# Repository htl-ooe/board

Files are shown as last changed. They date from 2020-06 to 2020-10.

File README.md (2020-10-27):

# HTL OOE HAT for Raspberry Pi
board schematic, layout and instructions on how to operate the board

## Installing the Operating System

### Downloading the Operating System
There are lots of operating Systems (Distributions) for the Raspberry Pi. Most of them are based on Linux.
The Foundation’s official supported operating system is [Raspberry Pi OS](https://www.raspberrypi.org/downloads/raspberry-pi-os/ "Raspberry Pi OS").
There are 3 Variants:
  * [Raspberry Pi OS with desktop and recommended software](https://downloads.raspberrypi.org/raspios_full_armhf_latest "Raspberry Pi OS full")
  * [Raspberry Pi OS with desktop](https://downloads.raspberrypi.org/raspios_armhf_latest "Raspberry Pi OS with Desktop")
  * [Raspberry Pi OS Lite (just Console, smallest in size)](hhttps://downloads.raspberrypi.org/raspios_lite_armhf_latest "Raspberry Pi OS Lite")

In our case [Raspberry Pi OS with desktop](https://downloads.raspberrypi.org/raspios_armhf_latest "Raspberry Pi OS with Desktop") is the the best choice.
You can not just copy the files to a Micro SD Card to install the Operating System. To boot Raspberry Pi OS you have to install the Operating System on the Micro SD Card.
Look at [Installing operating system images](https://www.raspberrypi.org/documentation/installation/installing-images/README.md "Installing operating system images") for how to do this. [balenaEtcher](https://www.balena.io/etcher/ "balena Etcher") installs itself to the Userprofile, take care of that when trying to use with different Accounts!
You will need administrative rights to format the Micro SD Card, so installing and using balena Etcher as Administrator is a good choice.
To be able to connect via ssh to the Raspberry Pi (headless) you can place the Files [ssh und wpa_supplicant.conf](https://www.raspberrypi.org/documentation/configuration/boot_folder.md "ssh und wpa_supplicant.conf") in the boot Folder of the Micro SD Card during the verify Cycle of  balena Etcher.
When using a SD Card to Micro SD Card Adapter, there is a Switch called **LOCK**. Take care, that the Switch is in the unlocked position (balena Etcher will tell you if the Micro SD Card is write protected).
When you access the Micro SD Card using Microsoft Windows, it asks for **formatting** the Device. **Don't do this!**
Now you can power up the Raspberry Pi with the plugged in Micro SD Card. If the Rasperry Pi is connected to a Monitor, you can you can read the Raspberry Pi's IP Address.
When you operate the Raspberry Pi headless you can use IP Scanners like the [Advanced IP Scanner](https://www.advanced-ip-scanner.com/ "Advanced IP Scanner") to get the IP Address.
Transfering Files is easy with [WinSCP](https://winscp.net/eng/download.php "WinSCP"). You can start a Terminal Program from within WinSCP itself or download [PuTTY](https://www.chiark.greenend.org.uk/~sgtatham/putty/latest.html "PuTTY").
When connected, you can enable **VNC** via
```console
pi@raspberrypi:~ $ sudo raspi-config
```
and use a Viewer like [VNC Viewer](https://www.realvnc.com/en/connect/download/viewer/ "VNC Viewer")

### Updating the Operating System and Installing Software

#### preparing APT for use with an Proxy
Create a new File called proxy.conf and edit it. You can use an Editor like **nano** or **vi**
```console
pi@raspberrypi:~ $ sudo touch /etc/apt/apt.conf.d/proxy.conf
pi@raspberrypi:~ $ sudo vi /etc/apt/apt.conf.d/proxy.conf
```
Add the following Lines to the empty File:
```code
Acquire {
  HTTP::proxy "http://proxy.htl-steyr.ac.at:8082/";
  HTTPS::proxy "https://proxy.htl-steyr.ac.at:8082/";
}
```
If you do not need the proxy (e.g. at home), you can just rename the File to disable the proxy:
```console
pi@raspberrypi:~ $ sudo mv /etc/apt/apt.conf.d/proxy.conf /etc/apt/apt.conf.d/proxy.conf.htl
```
#### Using APT
Using **apt-get** (Advanced Packaging Tool) you can update the Operating System and install Software.
The most important apt-get commands are:
| command | description |
| --- | --- |
| update | downloads the package lists from the repositories |
| upgrade | updates the list of available packages and their versions |
| install | installs one or more program package(s) |
| purge | removes a program package including the configuration|
apt-get needs the time and date to be set to an actual value! You can do this by typing
```console
pi@raspberrypi:~ $ sudo date -s "13 Jun 2020 09:20:00"
pi@raspberrypi:~ $ date # returns current time and date
```
If you have a ntp timeserver up and running you can edit
```console
pi@raspberrypi:~ $ sudo vi /etc/systemd/timesyncd.conf
```
to update the time via network.

To do the necessary software Maintenance you should enter
```console
pi@raspberrypi:~ $ sudo apt-get -y update && sudo apt-get -y dist-upgrade
```
Setting the Time Zone and enabling ntp (network time protocol)
```console
pi@raspberrypi:~ $ sudo timedatectl set-timezone Europe/Vienna
pi@raspberrypi:~ $ sudo timedatectl set-ntp true
```

## Device Tree
To manage ressources Linux uses the [Device Tree](https://www.raspberrypi.org/documentation/configuration/device-tree.md "Device Tree"). Parts of it are configured in the File [config.txt](https://www.raspberrypi.org/documentation/configuration/config-txt/README.md "config.txt").
You can also add devices via the EEPROM on a [HAT](https://github.com/raspberrypi/hats "HAT").
To configure devices [virtual Filesystems](https://en.wikipedia.org/wiki/Virtual_file_system "virtual Filesystems") (/dev, /sys, /proc) are frequently used.
### PWM
Our HAT uses PWM channels. The **root** user can access the onboard chanels.
If the user **pi** should use the pripheral, you have to give him the rights to do this:
Edit the File `/etc/udev/rules.d/99-com.rules`
```console
pi@raspberrypi:~ $ sudo vi /etc/udev/rules.d/99-com.rules
```
and change
```code
        chown -R root:gpio /sys/devices/platform/soc/*.pwm/pwm/pwmchip* && chmod -R 770 /sys/devices/platform/soc/*.pwm/pwm/pwmchip*\
```
to
```code
        chown -R root:gpio /sys/devices/platform/soc/*.pwm/pwm/pwmchip* && chmod -R 770 /sys/devices/platform/soc/*.pwm/pwm/pwmchip*;\
        chown -R root:gpio /sys/devices/platform/soc/*.i2c/i2c*/*/pwm/pwmchip* && chmod -R 770 /sys/devices/platform/soc/*.i2c/i2c*/*/pwm/pwmchip*\
```
mind the semicolon **;** to be added to the first Line!

Controlling the PWM Unit can be done in the virtual Filesystem `/sys/class/pwm/pwmchip*`.
When using **Python** [python-periphery](https://python-periphery.readthedocs.io/ "python-periphery") can access the PWM channels.
Keyboard, Mouse, Joysticks and Game Controllers can easily be accessed using [python-evdev](https://python-evdev.readthedocs.io/ "python-evdev")
#### Programing the HAT EEPROM
Download the latest Version of the **eepromutils** and compile the utils. You can also download the Repository (zip file) and unzip them in pi's homedirectory. Then you have to rename the directorys, so they do not contain "-master".
```console
pi@raspberrypi:~ $ sudo apt-get install -y git
pi@raspberrypi:~ $ git clone https://github.com/raspberrypi/hats.git
pi@raspberrypi:~ $ git clone https://github.com/htl-ooe/board.git
pi@raspberrypi:~ $ cd hats/eepromutils && make ; cd
```
```console
pi@raspberrypi:~ $ sudo dtc -@ -H epapr -O dtb -o "/boot/overlays/smartcar-V1-2.dtbo" -W no-unit_address_vs_reg './board/hat/smartcar-V1-2-overlay.dts'
```
compiles the device tree source file and copies it to `/boot/overlays`. You can test the overlayfile by adding the line
`dtoverlay=smartcar-V1-2` to [config.txt](https://www.raspberrypi.org/documentation/configuration/config-txt/README.md "config.txt")
```console
pi@raspberrypi:~ $ ./hats/eepromutils/eepmake ./board/hat/eeprom_settings-V1-2.txt ./board/hat/smartcar-V1-2.eep /boot/overlays/smartcar-V1-2.dtbo
```
generates the contents of the EEPROM

Disable the write protection with a piece of wire or calipers: 
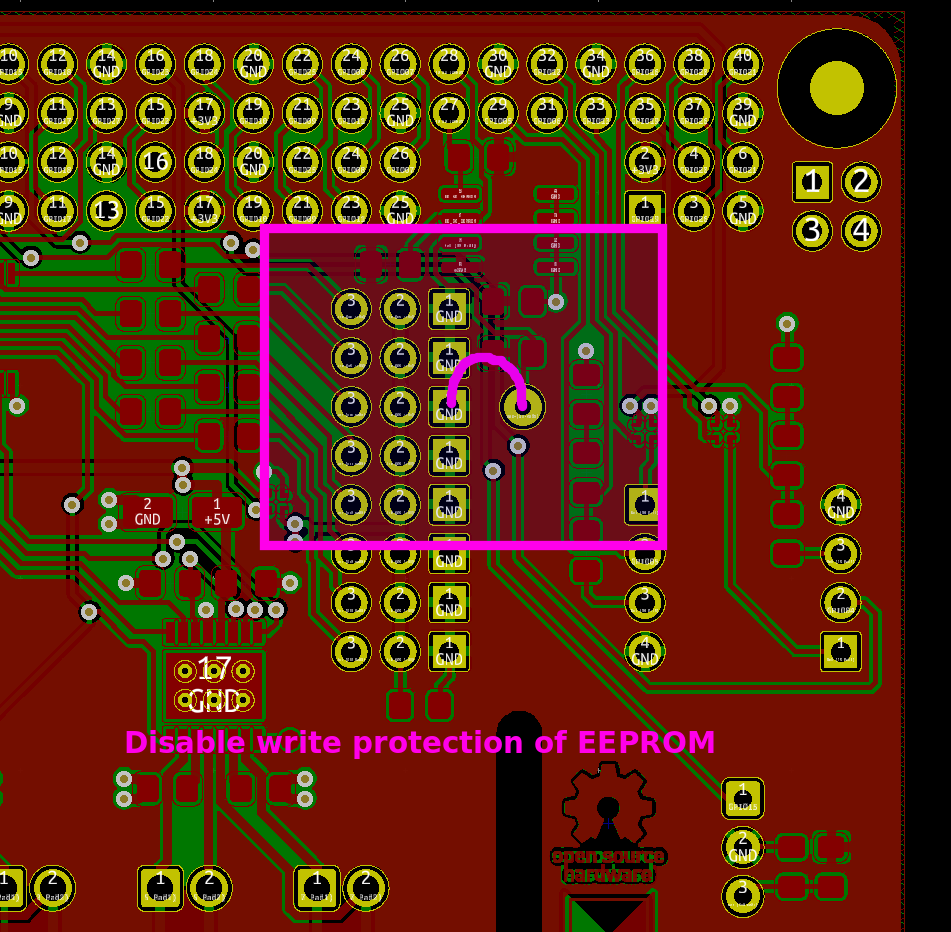
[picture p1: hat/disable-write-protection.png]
Disable the write protection


```console
pi@raspberrypi:~ $ sudo ./hats/eepromutils/eepflash.sh -w -f=./board/hat/smartcar-V1-2.eep -t=24c512
```
writes smartcar-V1-2.eep to the EEPROM, assumed that you disabled the Write Protection and i2c-0 can be enabled. Propably you need dtparam=i2c_vc=on in [config.txt](https://www.raspberrypi.org/documentation/configuration/config-txt/README.md "config.txt").

#### Reboot
```
pi@raspberrypi:~ $ sudo reboot
```

## Ultrasonic Sensors
### Compile modules install toolchain and headers
```console
pi@raspberrypi:~ $ sudo apt-get install -y raspberrypi-kernel-headers
```
installs the header Files for the Kernel
```console
pi@raspberrypi:~ $ git clone https://github.com/htl-ooe/board.git
pi@raspberrypi:~ $ sudo /home/pi/board/drivers/install.sh
```
compiles the srf04.c File and copies it to the propper directory. When you did this once you can copy the compiled module to another Raspberry Pi and do not have to compile (download the rpi headers) again.
## IR Receiver
install ir-keytable
```console
pi@raspberrypi:~ $ sudo apt-get install -y ir-keytable
```
select the desired Protocol (templates: /lib/udev/rc_keymaps) eg: rc6_mce
```console
pi@raspberrypi:~ $ sudo ir-keytable -p rc-5,rc-5-sz,jvc,sony,nec,sanyo,mce_kbd,rc-6,sharp,xmp -w /lib/udev/rc_keymaps/rc6_mce.toml
```
to test type
```console
pi@raspberrypi:~ $ ir-keytable --test
```
to bind actions (triggers) to a IR Key edit eg. /etc/triggerhappy/triggers.d/power.conf (new File)
and add the line **KEY_POWER		1	sudo /sbin/halt** to shutdown with the power key

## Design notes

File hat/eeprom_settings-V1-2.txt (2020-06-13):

########################################################################
# EEPROM settings text file
#
# Edit this file for your particular board and run through eepmake tool,
# then use eepflash tool to write to attached HAT ID EEPROM 
#
# Tools available:
#  eepmake   Parses EEPROM text file and creates binary .eep file
#  eepdump   Dumps a binary .eep file as human readable text (for debug)
#  eepflash  Write or read .eep binary image to/from HAT EEPROM
#
########################################################################

########################################################################
# Vendor info

# 128 bit UUID. If left at zero eepmake tool will auto-generate
# RFC 4122 compliant UUID
product_uuid 00000000-0000-0000-0000-000000000000

# 16 bit product id
product_id 0x0002

# 16 bit product version
product_ver 0x0001

# ASCII vendor string  (max 255 characters)
vendor "HTL Steyr"

# ASCII product string (max 255 characters)
product "Smart Car V1.2"

########################################################################
# GPIO bank settings, set to nonzero to change from the default.
# NOTE these setting can only be set per BANK, uncommenting any of
# these will force the bank to use the custom setting.

# drive strength, 0=default, 1-8=2,4,6,8,10,12,14,16mA, 9-15=reserved
gpio_drive 0

# 0=default, 1=slew rate limiting, 2=no slew limiting, 3=reserved
gpio_slew 0

# 0=default, 1=hysteresis disabled, 2=hysteresis enabled, 3=reserved
gpio_hysteresis 0

# If board back-powers Pi via 5V GPIO header pins:
# 0 = board does not back-power
# 1 = board back-powers and can supply the Pi with a minimum of 1.3A
# 2 = board back-powers and can supply the Pi with a minimum of 2A
# 3 = reserved
# If back_power=2 then USB high current mode will be automatically 
# enabled on the Pi
back_power 0

########################################################################
# GPIO pins, uncomment for GPIOs used on board
# Options for FUNCTION: INPUT, OUTPUT, ALT0-ALT5
# Options for PULL: DEFAULT, UP, DOWN, NONE
# NB GPIO0 and GPIO1 are reserved for ID EEPROM so cannot be set

#         GPIO  FUNCTION  PULL
#         ----  --------  ----
setgpio  2     ALT0     DEFAULT
setgpio  3     ALT0     DEFAULT
setgpio  4     OUTPUT     DEFAULT
setgpio  5     OUTPUT     DEFAULT
setgpio  6     INPUT     DEFAULT
#setgpio  7     INPUT     DEFAULT
#setgpio  8     INPUT     DEFAULT
#setgpio  9     INPUT     DEFAULT
#setgpio  10    INPUT     DEFAULT
#setgpio  11    INPUT     DEFAULT
setgpio  12    OUTPUT     DOWN
setgpio  13    OUTPUT     DOWN
#setgpio  14    INPUT     DEFAULT
setgpio  15    INPUT     DEFAULT
setgpio  16    INPUT     DEFAULT
#setgpio  17    INPUT     DEFAULT
#setgpio  18    INPUT     DEFAULT
#setgpio  19    INPUT     DEFAULT
#setgpio  20    INPUT     DEFAULT 
#setgpio  21    INPUT     DEFAULT 
#setgpio  22    INPUT     DEFAULT
setgpio  23    OUTPUT     DEFAULT
#setgpio  24    INPUT     DEFAULT
#setgpio  25    INPUT     DEFAULT
#setgpio  26    INPUT     DEFAULT
setgpio  27    OUTPUT     DEFAULT

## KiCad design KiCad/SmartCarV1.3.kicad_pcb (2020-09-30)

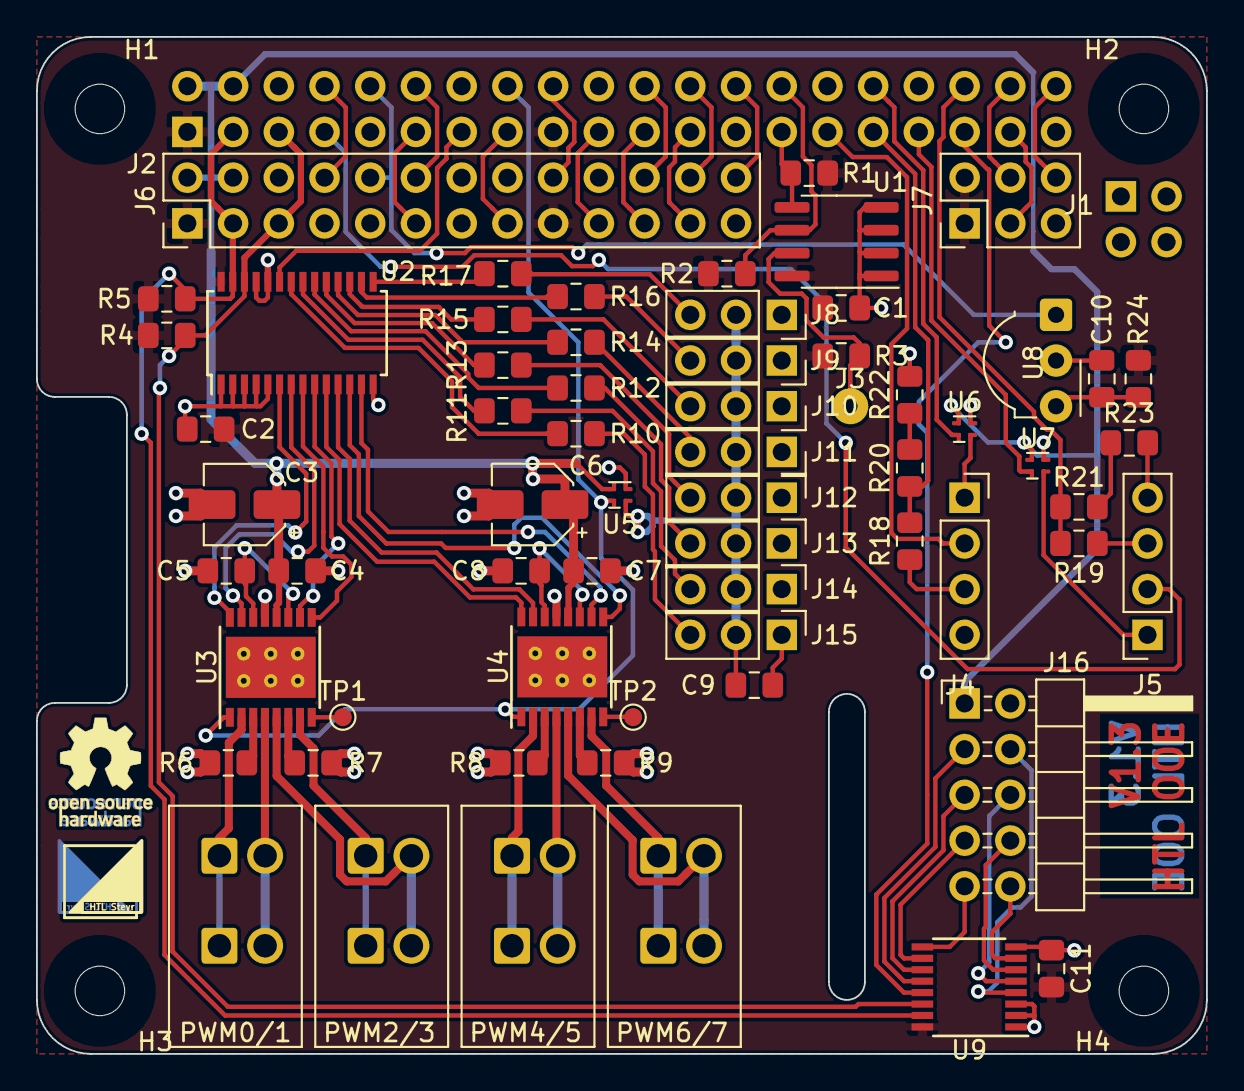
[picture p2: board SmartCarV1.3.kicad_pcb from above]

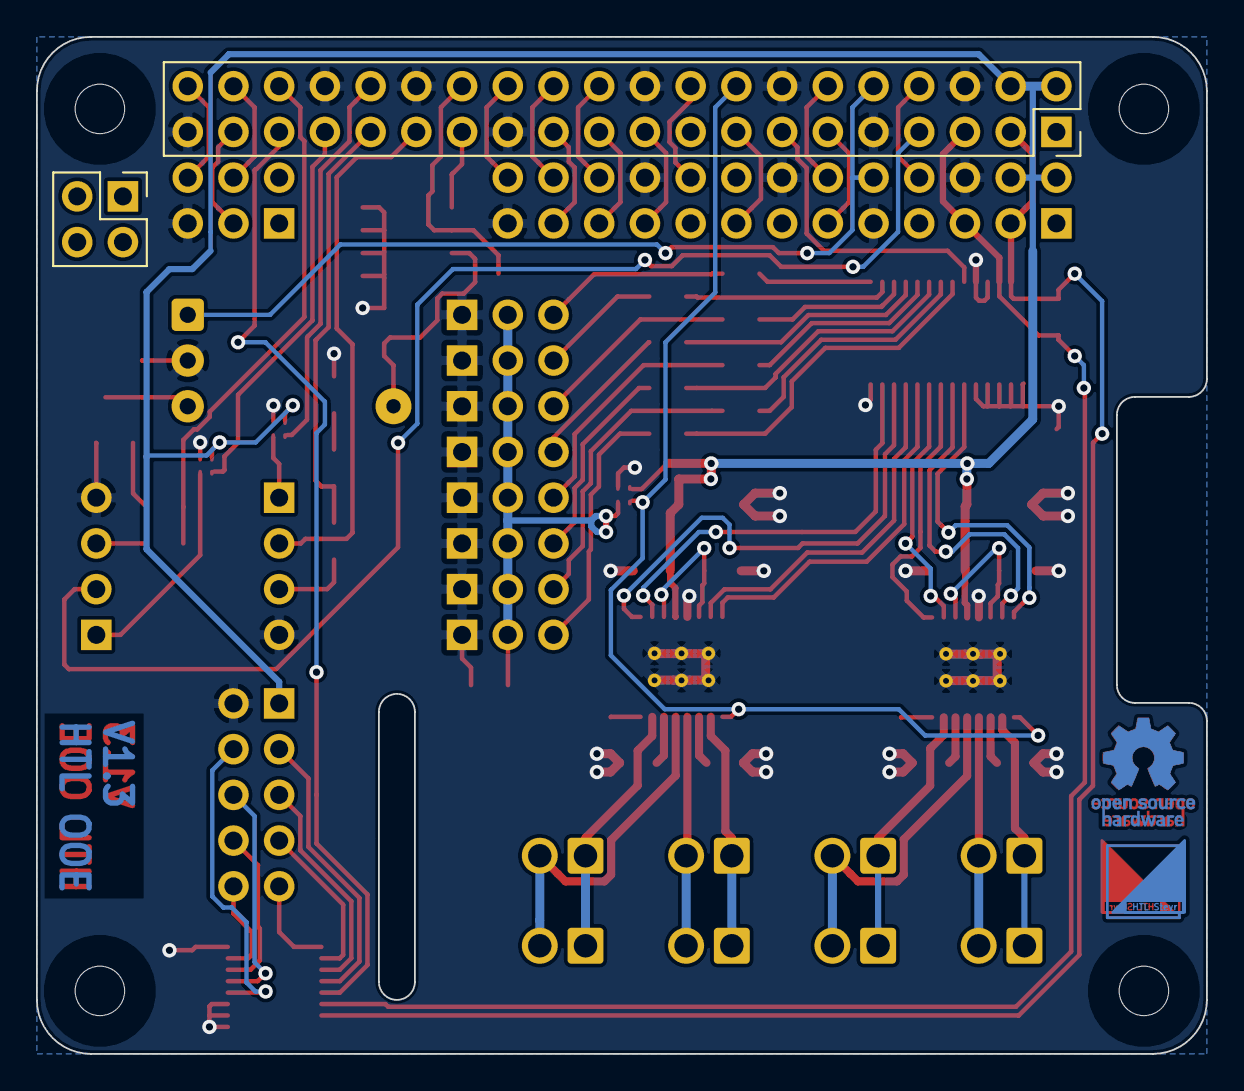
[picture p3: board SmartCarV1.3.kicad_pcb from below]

Board: 2 copper layers, 65.0 x 56.5 mm, 76 parts (4 on the bottom side), 88 nets.

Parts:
C1, C2, C4, C7, C9, C10, C11: 100nF; C_0805_2012Metric_Pad1.15x1.40mm_HandSolder
C3, C6: 10uF; CP_Elec_4x5.7
C5, C8: 2,2uF; C_0805_2012Metric_Pad1.15x1.40mm_HandSolder
H1, H2, H3, H4: MountingHole; MountingHole_2.7mm_M2.5
J1: PI4HAT; PinSocket_2x02_P2.54mm_Vertical
J2: PI40HAT; PinSocket_2x20_P2.54mm_Vertical
J3: Conn_01x01; SolderWirePad_1x01_Drill0.8mm
J4, J5: Conn_01x04; PinSocket_1x04_P2.54mm_Vertical
J6: Conn_02x13_Odd_Even; PinHeader_2x13_P2.54mm_Vertical
J7: Conn_02x03_Odd_Even; PinHeader_2x03_P2.54mm_Vertical
J8, J9, J10, J11: Conn_01x03; PinSocket_1x03_P2.54mm_Vertical
J12, J13, J14, J15: Conn_01x03; PinHeader_1x03_P2.54mm_Vertical
J16: Conn_02x05_Odd_Even; PinHeader_2x05_P2.54mm_Horizontal
Logo1, Logo3: HTL-Steyr-Logo_4x4mm_Copper
Logo2, Logo6: OSHW-Logo_5.7x6mm_Copper
Logo4: HTL-Steyr-Logo_4x4mm_SilkScreen
Logo7: OSHW-Logo_5.7x6mm_SilkScreen
PWM0/1, PWM2/3, PWM4/5, PWM6/7: Conn_01x02; TE_2834085-1_1x02_P2.54mm_45deg
R1, R2, R3, R4, R5, R18, R19, R20, R21, R22, R23: 3k9; R_0805_2012Metric_Pad1.15x1.40mm_HandSolder
R6, R7, R8, R9: 470m; R_0805_2012Metric_Pad1.15x1.40mm_HandSolder
R10, R11, R12, R13, R14, R15, R16, R17: 270; R_0805_2012Metric_Pad1.15x1.40mm_HandSolder
R24: 100; R_0805_2012Metric_Pad1.15x1.40mm_HandSolder
TP1, TP2: TestPoint_Probe; TestPoint_Pad_D1.0mm
U1: CAT24C512; SOIC-8_3.9x4.9mm_P1.27mm
U2: PCA9685PW; TSSOP-28_4.4x9.7mm_P0.65mm
U3, U4: DRV8848; HTSSOP-16-1EP_4.4x5mm_P0.65mm_EP3.4x5mm_Mask2.46x2.31mm_The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
U5, U6, U7: MIC94044YFL; MLF-4-1.2x1.2mm
U8: TSOP43xx; Vishay_MOLD-3Pin
U9: TCA9554DBQ; SSOP-16_3.9x4.9mm_P0.635mm

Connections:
+3V3: C1.1, C2.1, C11.2, J2.1, J2.17, J6.1, J6.17, J7.1, J7.2, R1.2, R2.2, R3.2, R4.2, R5.2, R24.1, U1.8, U2.28, U9.16
+5V: C3.1, C4.1, C6.1, C7.1, J2.2, J2.4, J6.2, J6.4, J16.1, U3.12, U4.12, U5.3, U6.3, U7.3
/GPIO04: J2.7, J5.2
/GPIO05: J2.29, J4.2
/GPIO06: J2.31, R18.2, R20.1
/GPIO07: J2.26, J6.26
/GPIO08: J2.24, J6.24
/GPIO09: J2.21, J6.21
/GPIO10: J2.19, J6.19
/GPIO11: J2.23, J6.23
/GPIO12: J2.32, U6.4
/GPIO13: J2.33, U7.4
/GPIO14: J2.8, J6.8
/GPIO15: J2.10, J6.10, U8.1
/GPIO16: J2.36, R19.2, R21.1
/GPIO17: J2.11, J6.11
/GPIO18: J2.12, J6.12
/GPIO19: J2.35, U9.13
/GPIO20: J2.38, J7.4
/GPIO21: J2.40, J7.6
/GPIO22: J2.15, J6.15
/GPIO23: J2.16, U3.1, U4.1, U5.4
/GPIO24: J2.18, J6.18
/GPIO25: J2.22, J6.22
/GPIO26: J2.37, J7.3
/GPIO27: J2.13, U2.23
/ID_SC_EEPROM: J2.28, R2.1, U1.6
/ID_SD_EEPROM: J2.27, R1.1, U1.5
/SCL1: J2.5, J6.5, R4.1, U2.26, U9.14
/SDA1: J2.3, J6.3, R5.1, U2.27, U9.15
GND: C1.2, C2.2, C3.2, C4.2, C5.2, C6.2, C7.2, C8.2, C9.2, C10.1, C11.1, J2.6, J2.9, J2.14, J2.20, J2.25, J2.30, J2.34, J2.39, J4.4, J5.4, J6.6, J6.9, J6.14, J6.20, J6.25, J7.5, J8.1, J9.1, J10.1, J11.1, J12.1, J13.1, J14.1, J15.1, J16.2, R6.2, R7.2, R8.2, R9.2, R22.2, R23.2, U1.1, U1.2, U1.3, U1.4, U2.1, U2.2, U2.3, U2.4, U2.5, U2.14, U2.24, U2.25, U3.13, U3.17, U4.13, U4.17, U5.2, U6.2, U7.2, U8.2, U9.1, U9.2, U9.3, U9.8
unnamed: C5.1, U3.11, U3.14
unnamed: C8.1, U4.11, U4.14
unnamed: C9.1, J8.2, J9.2, J10.2, J11.2, J12.2, J13.2, J14.2, J15.2, U5.1
unnamed: C10.2, R24.2, U8.3
unnamed: J3.1, R3.1, U1.7
unnamed: J4.1, U6.1
unnamed: J4.3, R18.1
unnamed: J5.1, U7.1
unnamed: J5.3, R19.1
unnamed: J8.3, R17.1
unnamed: J9.3, R16.1
unnamed: J10.3, R15.1
unnamed: J11.3, R14.1
unnamed: J12.3, R13.1
unnamed: J13.3, R12.1
unnamed: J14.3, R11.1
unnamed: J15.3, R10.1
unnamed: J16.3, U9.12
unnamed: J16.4, U9.4
unnamed: J16.5, U9.11
unnamed: J16.6, U9.5
unnamed: J16.7, U9.10
unnamed: J16.8, U9.6
unnamed: J16.9, U9.9
unnamed: J16.10, U9.7
unnamed: PWM0/1.1, U3.2
unnamed: PWM0/1.2, U3.4
unnamed: PWM2/3.1, U3.7
unnamed: PWM2/3.2, U3.5
unnamed: PWM4/5.1, U4.2
unnamed: PWM4/5.2, U4.4
unnamed: PWM6/7.1, U4.7
unnamed: PWM6/7.2, U4.5
unnamed: R6.1, U3.3
unnamed: R7.1, U3.6
unnamed: R8.1, U4.3
unnamed: R9.1, U4.6
unnamed: R10.2, U2.22
unnamed: R11.2, U2.21
unnamed: R12.2, U2.20
unnamed: R13.2, U2.19
unnamed: R14.2, U2.18
unnamed: R15.2, U2.17
unnamed: R16.2, U2.16
unnamed: R17.2, U2.15
unnamed: R20.2, R22.1
unnamed: R21.2, R23.1
unnamed: TP1.1, U3.8
unnamed: TP2.1, U4.8
unnamed: U2.6, U3.16
unnamed: U2.7, U3.15
unnamed: U2.8, U3.9
unnamed: U2.9, U3.10
unnamed: U2.10, U4.16
unnamed: U2.11, U4.15
unnamed: U2.12, U4.9
unnamed: U2.13, U4.10

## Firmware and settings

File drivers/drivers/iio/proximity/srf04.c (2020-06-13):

// SPDX-License-Identifier: GPL-2.0-or-later
/*
 * SRF04: ultrasonic sensor for distance measuring by using GPIOs
 *
 * Copyright (c) 2017 Andreas Klinger <ak@it-klinger.de>
 *
 * For details about the device see:
 * http://www.robot-electronics.co.uk/htm/srf04tech.htm
 *
 * the measurement cycle as timing diagram looks like:
 *
 *          +---+
 * GPIO     |   |
 * trig:  --+   +------------------------------------------------------
 *          ^   ^
 *          |<->|
 *         udelay(trigger_pulse_us)
 *
 * ultra           +-+ +-+ +-+
 * sonic           | | | | | |
 * burst: ---------+ +-+ +-+ +-----------------------------------------
 *                           .
 * ultra                     .              +-+ +-+ +-+
 * sonic                     .              | | | | | |
 * echo:  ----------------------------------+ +-+ +-+ +----------------
 *                           .                        .
 *                           +------------------------+
 * GPIO                      |                        |
 * echo:  -------------------+                        +---------------
 *                           ^                        ^
 *                           interrupt                interrupt
 *                           (ts_rising)              (ts_falling)
 *                           |<---------------------->|
 *                              pulse time measured
 *                              --> one round trip of ultra sonic waves
 */
#include <linux/err.h>
#include <linux/gpio/consumer.h>
#include <linux/kernel.h>
#include <linux/module.h>
#include <linux/of.h>
#include <linux/of_device.h>
#include <linux/platform_device.h>
#include <linux/property.h>
#include <linux/sched.h>
#include <linux/interrupt.h>
#include <linux/delay.h>
#include <linux/pm_runtime.h>
#include <linux/iio/iio.h>
#include <linux/iio/sysfs.h>

struct srf04_cfg {
	unsigned long trigger_pulse_us;
};

struct srf04_data {
	struct device		*dev;
	struct gpio_desc	*gpiod_trig;
	struct gpio_desc	*gpiod_echo;
	struct gpio_desc	*gpiod_power;
	struct mutex		lock;
	int			irqnr;
	ktime_t			ts_rising;
	ktime_t			ts_falling;
	struct completion	rising;
	struct completion	falling;
	const struct srf04_cfg	*cfg;
	int			startup_time_ms;
};

static const struct srf04_cfg srf04_cfg = {
	.trigger_pulse_us = 10,
};

static const struct srf04_cfg mb_lv_cfg = {
	.trigger_pulse_us = 20,
};

static irqreturn_t srf04_handle_irq(int irq, void *dev_id)
{
	struct iio_dev *indio_dev = dev_id;
	struct srf04_data *data = iio_priv(indio_dev);
	ktime_t now = ktime_get();

	if (gpiod_get_value(data->gpiod_echo)) {
		data->ts_rising = now;
		complete(&data->rising);
	} else {
		data->ts_falling = now;
		complete(&data->falling);
	}

	return IRQ_HANDLED;
}

static int srf04_read(struct srf04_data *data)
{
	int ret;
	ktime_t ktime_dt;
	u64 dt_ns;
	u32 time_ns, distance_mm;

	if (data->gpiod_power)
		pm_runtime_get_sync(data->dev);

	/*
	 * just one read-echo-cycle can take place at a time
	 * ==> lock against concurrent reading calls
	 */
	mutex_lock(&data->lock);

	reinit_completion(&data->rising);
	reinit_completion(&data->falling);

	gpiod_set_value(data->gpiod_trig, 1);
	udelay(data->cfg->trigger_pulse_us);
	gpiod_set_value(data->gpiod_trig, 0);

	if (data->gpiod_power) {
		pm_runtime_mark_last_busy(data->dev);
		pm_runtime_put_autosuspend(data->dev);
	}

	/* it should not take more than 20 ms until echo is rising */
	ret = wait_for_completion_killable_timeout(&data->rising, HZ/50);
	if (ret < 0) {
		mutex_unlock(&data->lock);
		return ret;
	} else if (ret == 0) {
		mutex_unlock(&data->lock);
		return -ETIMEDOUT;
	}

	/* it cannot take more than 50 ms until echo is falling */
	ret = wait_for_completion_killable_timeout(&data->falling, HZ/20);
	if (ret < 0) {
		mutex_unlock(&data->lock);
		return ret;
	} else if (ret == 0) {
		mutex_unlock(&data->lock);
		return -ETIMEDOUT;
	}

	ktime_dt = ktime_sub(data->ts_falling, data->ts_rising);

	mutex_unlock(&data->lock);

	dt_ns = ktime_to_ns(ktime_dt);
	/*
	 * measuring more than 6,45 meters is beyond the capabilities of
	 * the supported sensors
	 * ==> filter out invalid results for not measuring echos of
	 *     another us sensor
	 *
	 * formula:
	 *         distance     6,45 * 2 m
	 * time = ---------- = ------------ = 40438871 ns
	 *          speed         319 m/s
	 *
	 * using a minimum speed at -20 °C of 319 m/s
	 */
	if (dt_ns > 40438871)
		return -EIO;

	time_ns = dt_ns;

	/*
	 * the speed as function of the temperature is approximately:
	 *
	 * speed = 331,5 + 0,6 * Temp
	 *   with Temp in °C
	 *   and speed in m/s
	 *
	 * use 343,5 m/s as ultrasonic speed at 20 °C here in absence of the
	 * temperature
	 *
	 * therefore:
	 *             time     343,5     time * 106
	 * distance = ------ * ------- = ------------
	 *             10^6         2         617176
	 *   with time in ns
	 *   and distance in mm (one way)
	 *
	 * because we limit to 6,45 meters the multiplication with 106 just
	 * fits into 32 bit
	 */
	distance_mm = time_ns * 106 / 617176;

	return distance_mm;
}

static int srf04_read_raw(struct iio_dev *indio_dev,
			    struct iio_chan_spec const *channel, int *val,
			    int *val2, long info)
{
	struct srf04_data *data = iio_priv(indio_dev);
	int ret;

	if (channel->type != IIO_DISTANCE)
		return -EINVAL;

	switch (info) {
	case IIO_CHAN_INFO_RAW:
		ret = srf04_read(data);
		if (ret < 0)
			return ret;
		*val = ret;
		return IIO_VAL_INT;
	case IIO_CHAN_INFO_SCALE:
		/*
		 * theoretical maximum resolution is 3 mm
		 * 1 LSB is 1 mm
		 */
		*val = 0;
		*val2 = 1000;
		return IIO_VAL_INT_PLUS_MICRO;
	default:
		return -EINVAL;
	}
}

static const struct iio_info srf04_iio_info = {
	.read_raw		= srf04_read_raw,
};

static const struct iio_chan_spec srf04_chan_spec[] = {
	{
		.type = IIO_DISTANCE,
		.info_mask_separate =
				BIT(IIO_CHAN_INFO_RAW) |
				BIT(IIO_CHAN_INFO_SCALE),
	},
};

static const struct of_device_id of_srf04_match[] = {
	{ .compatible = "devantech,srf04", .data = &srf04_cfg},
	{ .compatible = "maxbotix,mb1000", .data = &mb_lv_cfg},
	{ .compatible = "maxbotix,mb1010", .data = &mb_lv_cfg},
	{ .compatible = "maxbotix,mb1020", .data = &mb_lv_cfg},
	{ .compatible = "maxbotix,mb1030", .data = &mb_lv_cfg},
	{ .compatible = "maxbotix,mb1040", .data = &mb_lv_cfg},
	{},
};

MODULE_DEVICE_TABLE(of, of_srf04_match);
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

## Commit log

2020-06-13 Add board schematics, layout and testprogram
    [SmartCarV1.2.kicad_pcb, SmartCarV1.2.sch]
2020-09-30 Add more gpio ports for switches, leds, etc.
    [SmartCarV1.3.kicad_pcb, SmartCarV1.3.sch]
2020-10-27 Update README.md
    add git clone https://github.com/htl-ooe/board.git to Ultrasonic Sensors section
2021-03-14 remove pinctl fron ultrasonic sensors, add pin-names to motor driver
